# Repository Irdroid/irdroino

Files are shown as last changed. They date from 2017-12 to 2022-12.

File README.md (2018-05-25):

### What is it?

Irdroino is a high quality infrared remote control shield for Arduino. Irdroino is powered by Irdroid’s experience in developing infrared products and it is a open source hardware project.
Use Irdroino to replicate signals from your existing remote controls, assign actions for the tx and rx keys of the shield. Control Air Conditioners, TVs , STBs, Music, and more. The Irdroino will help you also if you develop custom remote controls.

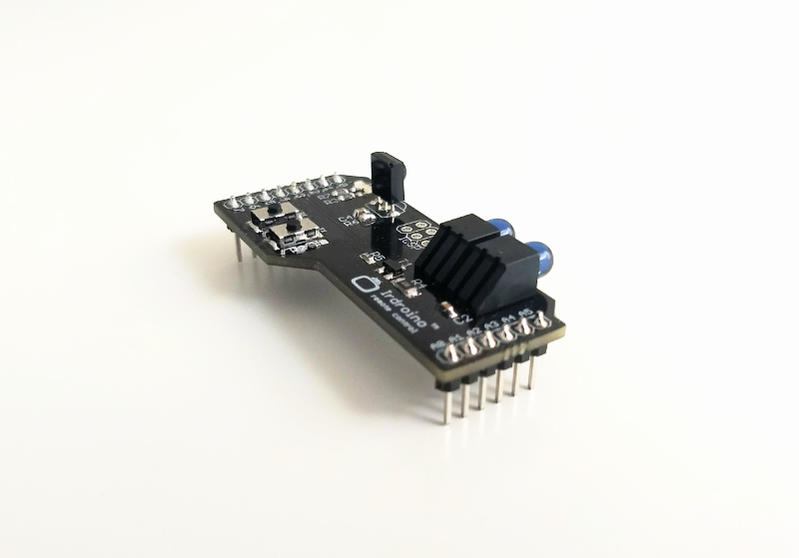
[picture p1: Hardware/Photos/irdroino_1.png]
Irdroino


The module is designed with low power consumption considerations in mind and it is suitable for low energy infrared remote controls design and development where you have to provide prolonged periods of unit inactivity (sleep modes) with just several micro amps of power consumption.

The Irdroino comes in a compact form factor, it extends the pin headers of your Arduino and at the same time provides infrared transmitter and receiver capabilities. The Irdroino uses optical signal amplification technique which gives additional boost and extended infrared transmit range. The open source hardware design gives you the freedom to modify Irdroino design and make your own custom IR shield. All the above features make Irdroino better in comparison with the rest of the infrared remote control shields for Arduino available on the market.

# Video

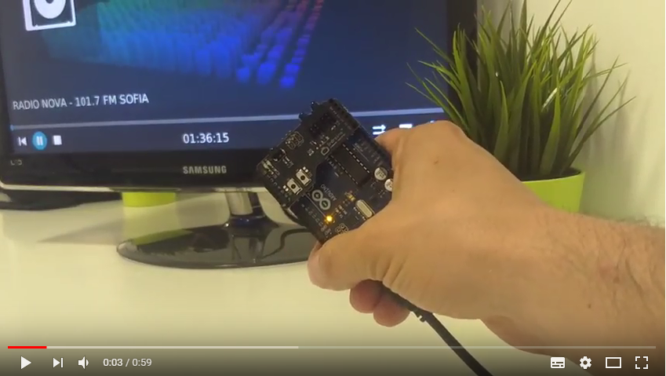
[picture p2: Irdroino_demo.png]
Watch the video (https://www.youtube.com/watch?v=hGpqAQRMAZQ)


### The Irdroino is compatible with :

* Arduino Boards
* Olimexino Boards

### Features:

* 2 High power IR Leds / uses optical signal amplification /
* 2 buttons for assigning custom IR commands
* High Quality IR receiver IC
* Status LEDs (for transmit and receive)
* Long pin headers that will allow you to use the free pins of your Arduino even if irdroino is on top of your Arduino
* Free and Open Source Software
* Open Source Hardware’s

### Why we made it?

I made this project because I believe in open source software and open source hardware, and I am passionate in developing free and open source infrared modules and things

### What makes it special?

The Irdroino is special, because it uses a unique optical signal amplification which give significantly improoved IR range. This gives a big advantage in comparison with similar products. It is open source hardware which gives the user a freedom and it has a high quality IR receiver IC. There are two sample Arduino Sketches in this repository. The first one is for recording and reproducing IR signals, using the two buttons for transmit and receive (record) remote control buttons. The second exaple sketch turns your Arduino into a PRONTO Hex USB IR Blaster (send / Transmit IR codes via Serial/USB). 

### Get a module:

* [Get a module from Irdroid](https://irdroid.eu/product/irdroino-infrared-shield-arduino/) 
* [Get a module from Tindie](https://www.tindie.com/products/irdroid/irdroino-infrared-shield-for-arduino/)

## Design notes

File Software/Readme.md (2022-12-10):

### Software Support

Here you will find two firmware types for the Irdroino infrared shield for Arduino

1. The irdroino_demo firmware contains code for record/playback/recreate infrared signals.
2. The Pronto USB IR Blaster firmware turns an Arduino equpped with Irdroino IR shield into a USB Pronto IR Blaster (Transmit PRONTO HEX Infrared codes)
3. The blast_ir is a set of command-line utilities for sending PRONTO HEX codes from the Terminal, using the PRONTO USB IR Blaster firmware

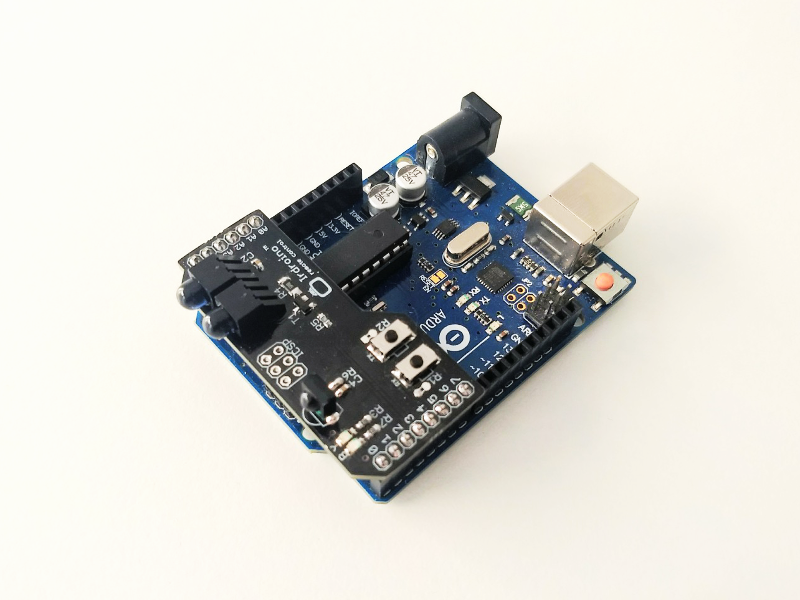
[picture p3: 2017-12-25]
Hardware/Photos/irdroino_3.png

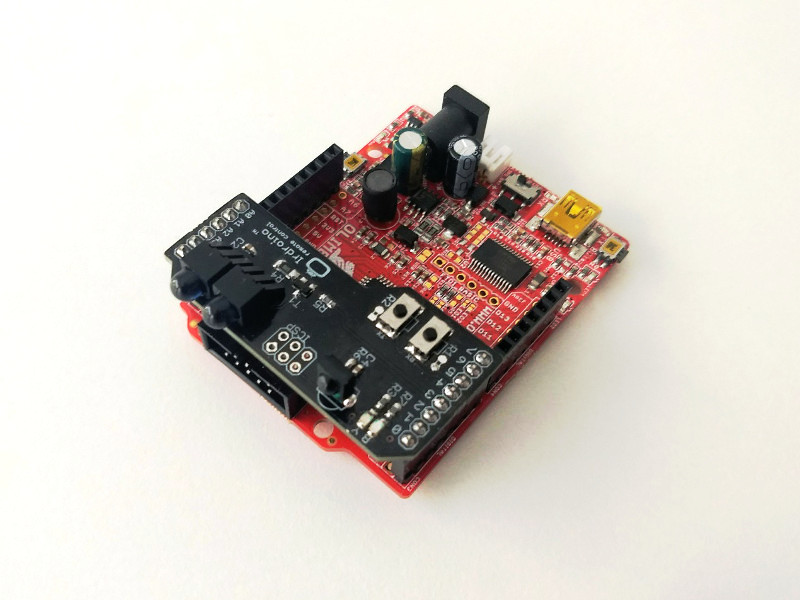
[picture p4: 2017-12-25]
Hardware/Photos/irdroino_4.jpg

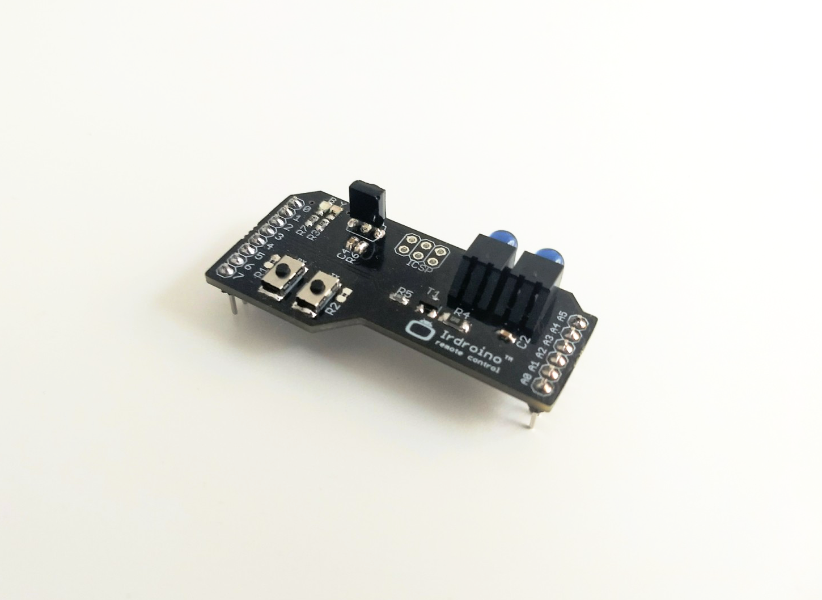
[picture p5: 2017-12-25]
Hardware/Photos/irdroino_2.png

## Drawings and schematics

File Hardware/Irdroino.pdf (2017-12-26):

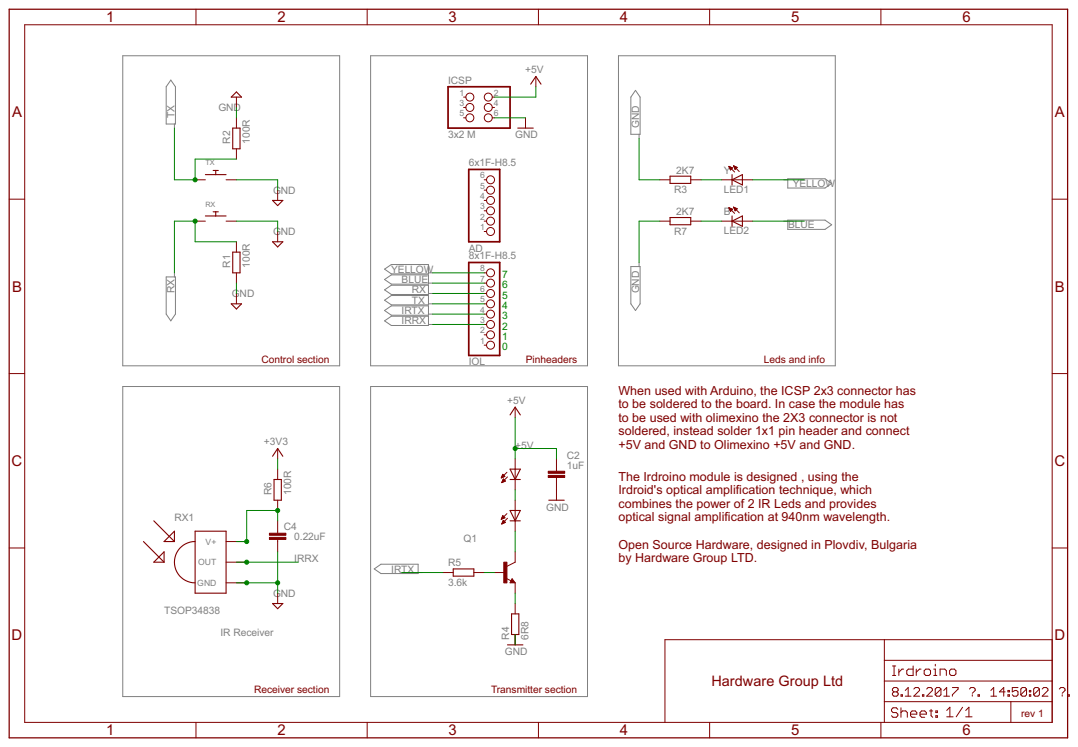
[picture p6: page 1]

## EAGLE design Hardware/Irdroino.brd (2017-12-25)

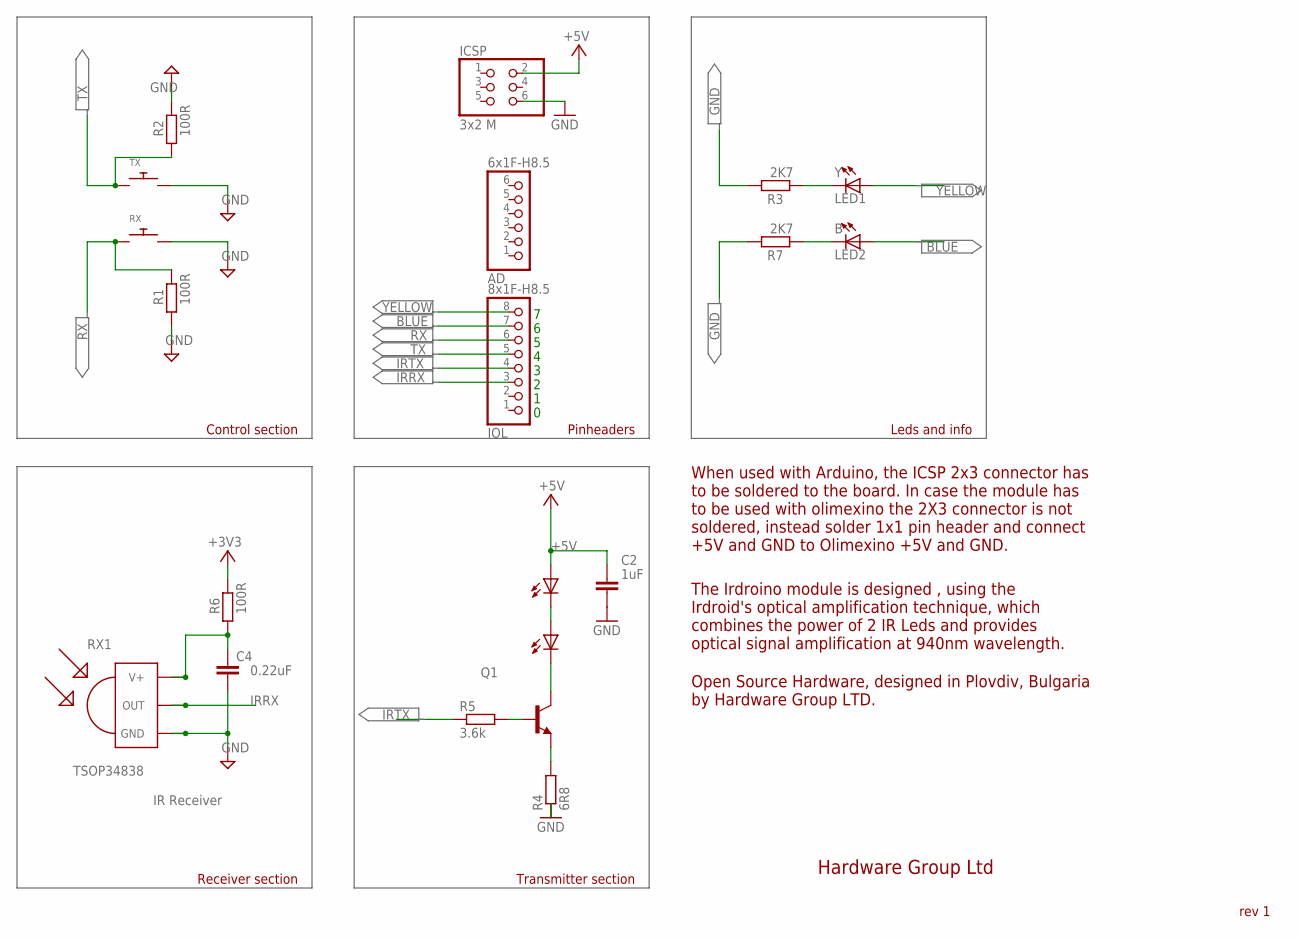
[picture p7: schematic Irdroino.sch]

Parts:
AD: 6x1F-H8.5; 1X06
B: LED2; CHIP-LED0805
C2: 1uF; C603@1
C4: 0.22uF; C603
ICSP: 3x2 M; 2X03
IOL: 8x1F-H8.5; 1X08
Q1: TRANSISTOR_BJT_NPN-SOT-23-BCE; SOT-23
R1, R2, R6: 100R; R603
R3, R7: 2K7; R603
R4: 6R8; R1206
R5: 3.6k; R0603
RX: SWITCH_PUSHBUTTONC&K_KSS; BTN_CK_KSS
RX1: TSOP34838; TSOP18XX
TX: SWITCH_PUSHBUTTONC&K_KSS; BTN_CK_KSS
U$5, U$7: IRLED5MM; IRLED_HOLDER
Y: LED1; CHIP-LED0805

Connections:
+5V: C2.1, ICSP.2, R6.2, U$7.A
A: Q1.2 (C), U$5.K (C)
BLUE: B.A, IOL.7
GND: C2.2, C4.2, ICSP.6, R1.1, R2.2, R3.1, R4.1, R7.1, RX.P$2, RX1.GND, TX.P$2
IRRX: IOL.3, RX1.OUT
IRTX: IOL.4, R5.1
K: Q1.3 (E), R4.2
unnamed: U$5.A, U$7.K (C)
unnamed: R3.2, Y.C
unnamed: B.C, R7.2
unnamed: Q1.1 (B), R5.2
unnamed: C4.1, R6.1, RX1.VCC (V+)
RX: IOL.6, R1.2, RX.P$1
TX: IOL.5, R2.1, TX.P$1
YELLOW: IOL.8, Y.A

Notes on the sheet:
RX1
TSOP34838
IR Receiver
Receiver section
Transmitter section
Control section
Leds and info
Pinheaders
Hardware Group Ltd
rev 1
When used with Arduino, the ICSP 2x3 connector has to be soldered to the board. In case the module has to be used with olimexino the 2X3 connector is not soldered, instead solder 1x1 pin header and connect +5V and GND to Olimexino +5V and GND.
The Irdroino module is designed , using the Irdroid's optical amplification technique, which combines the power of 2 IR Leds and provides optical signal amplification at 940nm wavelength.
Open Source Hardware, designed in Plovdiv, Bulgaria by Hardware Group LTD.

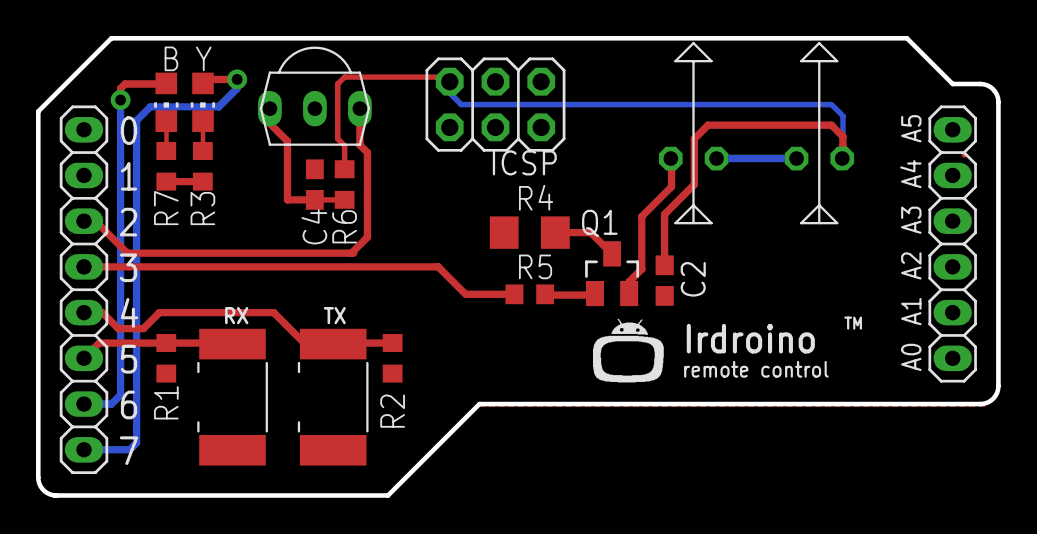
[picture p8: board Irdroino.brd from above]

Board: 2 copper layers, 53.3 x 25.4 mm, 21 parts (0 on the bottom side), 15 nets.

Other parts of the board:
U$2: IRDROIDLOGO

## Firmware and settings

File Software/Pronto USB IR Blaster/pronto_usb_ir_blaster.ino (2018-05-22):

/*
Send Pronto Hex via Irdroino shield connected to Arduino Pin D9 (make a jumper wire connection between pin 9 and pin 3).

 Sample usage:
 SEND 0000 0067 0000 000d 0060 0018 0030 0018 0030 0018 0030 0018 0030 0018 0018 0018 0030 0018 0018 0018 0030 0018 0018 0018 0018 0018 0018 0018 0018 03de
  
 Based on https://github.com/stephenong/Arduino-IR-Remote-Control-Player
 */


#include <avr/interrupt.h>
#include <stdio.h>
#include <avr/pgmspace.h>
#include <stdint.h>
#include <avr/io.h>
#define IR_PORT PORTB
#define IR_PIN PINB
#define IR_DDR DDRB
#define IR_BV _BV(1)
#define IR_OCR OCR1A
#define IR_TCCRnA TCCR1A
#define IR_TCCRnB TCCR1B
#define IR_TCNTn TCNT1
#define IR_TIFRn TIFR1
#define IR_TIMSKn TIMSK1
#define IR_TOIEn TOIE1
#define IR_ICRn ICR1
#define IR_OCRn OCR1A
#define IR_COMn0 COM1A0
#define IR_COMn1 COM1A1
#define PRONTO_IR_SOURCE 0 // Pronto code byte 0
#define PRONTO_FREQ_CODE 1 // Pronto code byte 1
#define PRONTO_SEQUENCE1_LENGTH 2 // Pronto code byte 2
#define PRONTO_SEQUENCE2_LENGTH 3 // Pronto code byte 3
#define PRONTO_CODE_START 4 // Pronto code byte 4

static const uint16_t *ir_code = NULL;
static uint16_t ir_cycle_count = 0;
static uint32_t ir_total_cycle_count = 0;
static uint8_t ir_seq_index = 0;
static uint8_t ir_led_state = 0;

void ir_on()
{
  IR_TCCRnA |= (1<<IR_COMn1) + (1<<IR_COMn0);
  ir_led_state = 1;
}

void ir_off()
{
  IR_TCCRnA &= ((~(1<<IR_COMn1)) & (~(1<<IR_COMn0)) );
  ir_led_state = 0;
}

void ir_toggle()
{
  if (ir_led_state)
    ir_off();
  else
    ir_on();
}

void ir_start(uint16_t *code)
{
  ir_code = code;
  IR_PORT &= ~IR_BV; // Turn output off
  IR_DDR |= IR_BV; // Set it as output
  IR_TCCRnA = 0x00; // Reset the pwm
  IR_TCCRnB = 0x00;
  uint16_t top = ( (F_CPU/1000000.0) * code[PRONTO_FREQ_CODE] * 0.241246 ) - 1;
  IR_ICRn = top;
  IR_OCRn = top >> 1;
  IR_TCCRnA = (1<<WGM11);
  IR_TCCRnB = (1<<WGM13) | (1<<WGM12);
  IR_TCNTn = 0x0000;
  IR_TIFRn = 0x00;
  IR_TIMSKn = 1 << IR_TOIEn;
  ir_seq_index = PRONTO_CODE_START;
  ir_cycle_count = 0;
  ir_on();
  IR_TCCRnB |= (1<<CS10);
}

#define TOTAL_CYCLES 80000 

ISR(TIMER1_OVF_vect) {
  uint16_t sequenceIndexEnd;
  uint16_t repeatSequenceIndexStart;
  ir_total_cycle_count++;
  ir_cycle_count++;

  if (ir_cycle_count== ir_code[ir_seq_index]) {
    ir_toggle();
    ir_cycle_count = 0;
    ir_seq_index++;
    sequenceIndexEnd = PRONTO_CODE_START +
      (ir_code[PRONTO_SEQUENCE1_LENGTH]<<1) +
      (ir_code[PRONTO_SEQUENCE2_LENGTH]<<1);

    repeatSequenceIndexStart = PRONTO_CODE_START +
      (ir_code[PRONTO_SEQUENCE1_LENGTH]<<1);

    if (ir_seq_index >= sequenceIndexEnd ) {
      ir_seq_index = repeatSequenceIndexStart;

      if(ir_total_cycle_count>TOTAL_CYCLES) {
        ir_off();
        TCCR1B &= ~(1<<CS10);
      }
    }
  }
}

void ir_stop()
{
  IR_TCCRnA = 0x00; // Reset the pwm
  IR_TCCRnB = 0x00;
}

const uint16_t inputLength = 512;

void setup() {
  Serial.begin(9600);
  Serial.println("READY");
}

void loop()
{
  if ( Serial.available() > 0 )
  {
    static char input[inputLength];
    static uint16_t i;
    char c = Serial.read();

    if ( c != '\r' && c != '\n' && i < inputLength-1)
      input[i++] = c;

    else
    {
      input[i] = '\0';
      i = 0;

      uint16_t array[80];
      uint16_t j = 0;

      if ( !strncmp(input, "SEND", 4) )
      {
        char* p = input+4;

        while ( (p = strchr(p, ' ')) != NULL )
          array[j++] = strtol(p, &p, 16);

        ir_start(array);
        Serial.print("SENT ");
        for ( uint8_t i = 0; i < j; i++ )
        {
          Serial.print ("0x");
          Serial.print (array[i], HEX);
          Serial.print(" ");
        }


        Serial.println();
      }
    }
  }
}

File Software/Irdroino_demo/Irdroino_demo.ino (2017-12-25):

/*  
 *  IR Remote Module
 *  
 *  Copyright (C) Libelium Comunicaciones Distribuidas S.L. 
 *  http://www.libelium.com 
 *  
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
 *  Version:           1.0
 *  Design:            David Gascón 
 *  Implementation:    Luis Martin
 */

// We need to use the 'raw' pin reading methods
// because timing is very important here and the digitalRead()
// procedure is slower!

#define IRpin_PIN PIND
#define IRpin 2

// The maximum pulse we'll listen for - 65 milliseconds is a long time
#define MAXPULSE 1000

// Timing resolution 
#define RESOLUTION 20

int IRledPin =  3;      // IR emitter LED connected to digital pin 3
int orangeLedPin =  7;  // Orange LED connected to digital pin 7
int buttonPin1 = 4;     // "Send" push-button connected to digital pin 4
int blueLedPin =  6;    // Blue LED connected to digital pin 6
int buttonPin2 = 5;     // "Receive" push-button connected to digital pin 5

int buttonState1 = 0;        
int buttonState2 = 0;

// Store up to 100 pulse pairs 
uint16_t pulses[100][2]; // Pair is high and low pulse
uint8_t currentpulse = 0; // Index for pulses we're storing
uint8_t sendpulse = 0; // Index for send pulses

void setup(void) {
  // Initialize the Orange LED pin as an output
  pinMode(orangeLedPin, OUTPUT);      
  // Initialize the "Send" push-button pin as an input
  pinMode(buttonPin1, INPUT_PULLUP);  
  // Initialize the Orange LED pin as an output
  pinMode(blueLedPin, OUTPUT);      
  // Initialize the "Send" push-button pin as an input
  pinMode(buttonPin2, INPUT_PULLUP);
  // Set uart baudrate
  Serial.begin(9600);
}

void loop(void) {
   // Read the state of the "Send" push-button value
  buttonState1 = digitalRead(buttonPin1);
  // Read the state of the "Receive" push-button value
  buttonState2 = digitalRead(buttonPin2);
 
if (buttonState1 == LOW) {   
    Serial.println("Sending IR signal");
    digitalWrite(orangeLedPin, HIGH); 
    delay(200);
    digitalWrite(orangeLedPin, LOW); 
    delay(200);
    
    SendIRCode();
    //delay(15);  // wait 15 milliseconds before sending it again
    //SendIRCode();  // repeat IR code if it is neccesary
 
    delay(250);  // wait 5 seconds to resend the code
    }

 if ((buttonState2==LOW) || (currentpulse != 0)){
   
   if (buttonState2==LOW){
    Serial.println("Ready to decode IR!");
    digitalWrite(blueLedPin, HIGH); 
    delay(200);
    digitalWrite(blueLedPin, LOW); 
    delay(200);
   }

  uint16_t highpulse, lowpulse; // Temporary storage timing
  highpulse = lowpulse = 0; // Start out with no pulse length
  
    while (IRpin_PIN & (1 << IRpin)) {
     // count off another few microseconds
     highpulse++;
     delayMicroseconds(RESOLUTION);

     // If the pulse is too long, we 'timed out' - either nothing
     // was received or the code is finished, so print what
     // we've grabbed so far, and then reset
     if ((highpulse >= MAXPULSE) && (currentpulse != 0)) {
       printpulses();
       sendpulse=currentpulse;
       currentpulse=0;
       return;
     }
  }
  // we didn't time out so lets stash the reading
  pulses[currentpulse][0] = highpulse;
  
  // same as above
  while (! (IRpin_PIN & _BV(IRpin))) {
     // pin is still LOW
     lowpulse++;
     delayMicroseconds(RESOLUTION);
     if ((lowpulse >= MAXPULSE) && (currentpulse != 0)) {
       printpulses();
       sendpulse=currentpulse;
       currentpulse=0;
       return;
     }
  }
  pulses[currentpulse][1] = lowpulse;

  // we read one high-low pulse successfully, continue!
  currentpulse++;
  
 }
}

void printpulses(void) {
  Serial.println("\n\r\n\rReceived:");
  for (uint8_t i = 0; i < currentpulse; i++) {
  
    if (i != 0){
    Serial.print("delayMicroseconds(");
    Serial.print(pulses[i][0] * RESOLUTION);
    Serial.println(");");
    }
    Serial.print("pulseIR(");
    Serial.print(pulses[i][1] * RESOLUTION);
    Serial.println(");");
  }
  delay(1000);
  digitalWrite(orangeLedPin, HIGH); 
  delay(200);
  digitalWrite(orangeLedPin, LOW); 
  delay(200);
  
/*  // Print it in a 'array' format
  Serial.println("int IRsignal[] = {");
  Serial.println("// ON, OFF (in 10's of microseconds)");
  for (uint8_t i = 0; i < currentpulse-1; i++) {
    Serial.print("\t"); // tab
    Serial.print(pulses[i][1] * RESOLUTION / 10, DEC);
    Serial.print(", ");
    Serial.print(pulses[i+1][0] * RESOLUTION / 10, DEC);
    Serial.println(",");
  }
  Serial.print("\t"); // tab
  Serial.print(pulses[currentpulse-1][1] * RESOLUTION / 10, DEC);
  Serial.print(", 0};");
*/ 
}

// This procedure sends a 38KHz pulse to the IRledPin for a certain # of microseconds.
void pulseIR(long microsecs) {
 
  cli();  // Turn off any background interrupts
 
  while (microsecs > 0) {
   // 38 kHz is about 13 microseconds high and 13 microseconds low
   digitalWrite(IRledPin, HIGH);  // 3 microseconds
   delayMicroseconds(7);         /* hang out for 10 microseconds, 
                                     you can also change this to 9 if its not working */
   digitalWrite(IRledPin, LOW);   // 3 microseconds
   delayMicroseconds(7);         /* hang out for 10 microseconds, 
                                     you can also change this to 9 if its not working */
 
   // So 26 microseconds altogether
   microsecs -= 26;
  }
 
  sei();  // Turn them back on
}
 
void SendIRCode() {

  for (uint8_t i = 0; i < sendpulse; i++) {
  
    if (i != 0){
    delayMicroseconds(pulses[i][0] * RESOLUTION);
    }
    
    pulseIR(pulses[i][1] * RESOLUTION);
  }
}

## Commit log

2017-12-25 Updated code and Documentation
    Updated code and Documentation
    [Irdroino.brd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]
2017-12-26 Added a schematic in PDF
    Added a schematic in PDF in the hardware folder

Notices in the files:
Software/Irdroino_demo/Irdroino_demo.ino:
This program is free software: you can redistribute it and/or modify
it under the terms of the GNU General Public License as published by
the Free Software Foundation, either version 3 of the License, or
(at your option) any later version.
